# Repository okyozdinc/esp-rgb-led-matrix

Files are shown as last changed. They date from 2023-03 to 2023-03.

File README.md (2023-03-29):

# PIXELIX <!-- omit in toc -->
PIXELIX

Full RGB LED matrix, based on an ESP32 and WS2812B LEDs.






pixelix (https://www.youtube.com/watch?v=dik8Rm6f3o0 "Pixelix")
pixelix (https://www.youtube.com/watch?v=UCjJCI5JShY "Pixelix - Remote Button")

- [Motivation](#motivation)
- [Overview](#overview)
  - [Original setup](#original-setup)
  - [Others](#others)
- [Installation](#installation)
- [Very First Startup](#very-first-startup)
  - [Variant 1: Configure wifi station SSID and passphrase with the browser](#variant-1-configure-wifi-station-ssid-and-passphrase-with-the-browser)
  - [Variant 2: Configure wifi station SSID and passphrase with the terminal](#variant-2-configure-wifi-station-ssid-and-passphrase-with-the-terminal)
  - [Pixelix Is Ready](#pixelix-is-ready)
- [User Interface](#user-interface)
- [Documentation](#documentation)
- [Used Libraries](#used-libraries)
- [FAQ](#faq)
  - [Where to change panel topology of the LED matrix?](#where-to-change-panel-topology-of-the-led-matrix)
  - [How to change text properties?](#how-to-change-text-properties)
  - [The display only shows a error code, like "E4". What does that mean?](#the-display-only-shows-a-error-code-like-e4-what-does-that-mean)
  - [How can I use animated icons?](#how-can-i-use-animated-icons)
  - [How do I know that my sensor is recognized?](#how-do-i-know-that-my-sensor-is-recognized)
  - [Why do I see sometimes values from the LDR in the SensorPlugin, although no LDR is installed?](#why-do-i-see-sometimes-values-from-the-ldr-in-the-sensorplugin-although-no-ldr-is-installed)
  - [How can I use alternative icons?](#how-can-i-use-alternative-icons)
  - [Is it possible to use a font with 8px height?](#is-it-possible-to-use-a-font-with-8px-height)
  - [How to configure the date/time format?](#how-to-configure-the-datetime-format)
- [Issues, Ideas And Bugs](#issues-ideas-and-bugs)
- [License](#license)
- [Contribution](#contribution)

# Motivation
I want to have a remote display to show multiple kind of information, running 24/7 reliable. Connected over wifi to the local network, it can be controlled via REST API or websocket.

| Some impressions | |
| - | - |
| TimePlugin | DatePlugin |
| IconTextLampPlugin | IconTextPlugin |
| WifiStatusPlugin | ... |

# Overview

The firmware contains a plugin concept (at compile time) to provide different functionalities. Each plugin can create its own layout and place the information as required. If you are only interested in showing just text provided via REST API, choose the JustTextPlugin. It uses the whole display size and will scroll text automatically. Sometimes in front of the text a nice icon is required, in this case choose the IconTextPlugin. These are only examples and you will find more in the [plugin list](./doc/PLUGINS.md).

A little bit more detail about the generic plugins and the first idea can be found in this [rough overview](./doc/Overview.pdf).

## Original setup
The original setup during development and the first release was:
* [ESP32 DevKitV1](https://github.com/playelek/pinout-doit-32devkitv1)
* WS2812B 5050 8x32 RGB Flexible LED Matrix Panel
* Power supply 5 V / 4 A

The following shows the absolute minimal wiring setup:

PixelixMinimalSetup

> :warning: **If you power all via USB**: Be very careful, because it may destroy your esp32 board if the LED current gets too high. Avoid increasing the LED display brightness or filling it complete with white pixels. Please use a external power supply with at least 5V / 4A.

## Others

In the meantime several other boards are supported as well. You can see them in the platformio configuration (platformio.ini) or the [list of boards](./doc/boards/README.md).

Additional supported variants, which were original not in focus:
* [LILYGO&reg; TTGO T-Display ESP32 WiFi and Bluetooth Module Development Board For Arduino 1.14 Inch LCD](http://www.lilygo.cn/prod_view.aspx?TypeId=50033&Id=1126&FId=t3:50033:3)
* [LILYGO&reg; T-Display ESP32-S3 1.9 inch ST7789 LCD Display Touch Screen Development Board](https://www.lilygo.cc/products/t-display-s3)

Although Pixelix was designed to show information, that is pushed or pulled via REST API, the following sensors can be directly connected and evaluated:
* Temperature and humidity sensors DHTx
* Temperature and humidity sensors SHT3x
* Digitial microphone INMP441 for some sound reactive stuff.

# Installation
The following steps are necessary for the first time and to get PIXELIX initial running on the target. Once it runs, later on the firmware and filesystem can be updated via the PIXELIX webinterface.

1. Setup the [toolchain](./doc/config/TOOLCHAIN-INSTALLATION.md).
2. [Build the software](./doc/config/SW-BUILD.md) and check whether the toolchain works.
3. [Upload/Update the software and firmware](./doc/config/SW-UPDATE.md) to the target.
4. Verify that the LED panel topology is correct and you see the "Hello World" on the display.

Note, that the LED panel topology and the display width/height can currently not be changed in the web interface. If its necessary, adapt first in ```./lib/HalLedMatrix/Board.h``` the _width_ and _height_ according your LED matrix. In the ```./lib/HalLedMatrix/LedMatrix.h``` file you have to change the member variable _m\_topo_ according to your physical panel topology. Take a look how your pixels are wired on the pcb and use the following page to choose the right one: https://github.com/Makuna/NeoPixelBus/wiki/Layout-objects

# Very First Startup
If the device starts the very first time, the wifi station SSID and passphrase settings are empty. They can be configured in two possible ways:
1. Using the browser and set them in the captive portal.
2. Using a terminal connecting via usb.

## Variant 1: Configure wifi station SSID and passphrase with the browser
Restart the device and keep the button pressed until it shows the SSID of the wifi access point, spawned by Pixelix. Search for it with your mobile device and connect.
* SSID: **pixelix**
* Passphrase: **Luke, I am your father.**

Depended on the type of device you are using for connecting to Pixelix, you may get a notification that further information is necessary and automatically routed to the captive portal. In any other case enter the URL http://192.168.4.1 in the browser address field.

Use the following default credentials to get access to the Pixelix webinterface:
* User: **luke**
* Password: **skywalker**

## Variant 2: Configure wifi station SSID and passphrase with the terminal
Connect Pixelix with your PC via usb and start a terminal. Use the following commands to set the wifi SSID and passphrase of your home wifi network:
* Write wifi passphrase: ```write wifi passphrase <your-passphrase>```
* Write wifi SSID: ```write wifi ssid <your-ssid>```
* Restart Pixelix: ```reset```

## Pixelix Is Ready
After configuration, restart again and voila, Pixelix will be available in your wifi network.

For changing whats displayed, go to its webinterface. Use the same credentials than for the captive portal in variant 1. In the "Display" page you can change it according to your needs.

# User Interface
* The user button provides several features:
    * On short pulse: Activates the next slot.
    * Two short pulses: Activates next fade effect.
    * Five short pulses: IP address is shown.
    * Long pressed: Increases the display brightness until maximum and then decreases until minimum. After that it will again increases it and so on.
* If the display's location is hard to reach, the virtual user button can be used. It is controllable via REST API and perfect for remote buttons like the [Shelly Button 1](https://shelly.cloud/products/shelly-button-1-smart-home-automation-device/).
* If a ambilight sensor (LDR) is connected, the display brightness is automatically adapted.
* The web interface provides the possibility to install plugins, control their duration in the slots and etc.
* Some plugin's spawn a dedicated REST API, see the web page of the plugin or have a look to the REST API documentation.

Note, the websocket interface is currently only used as a service in the web interface.

# Documentation
For more information, see the [documentation](./doc/README.md).

# Used Libraries
* [Arduino](https://github.com/platformio/platform-espressif32) - ESP32 Arduino framework - Apache-2.0 License
* [NeoPixelBus](https://github.com/Makuna/NeoPixelBus) - Controlling the LED matrix with hardware support (RMT) - LGPL-3.0 License
* [ESPAsyncWebServer](https://github.com/me-no-dev/ESPAsyncWebServer) - Webserver - LGPL-2.1 License
* [AsyncTCPSock](https://github.com/yubox-node-org/AsyncTCPSock) - TCP library, Reimplementation of the API of me-no-dev/AsyncTCP using high-level BSD sockets - LGPL-3.0 License
* [ArduinoJson](https://arduinojson.org/) - JSON handling - MIT License
* [StreamUtils](https://github.com/bblanchon/ArduinoStreamUtils) - Stream utilities - MIT License
* [Bootstrap](https://getbootstrap.com/) - CSS Framework - MIT License
* [POPPER JS](https://popper.js.org/) - POPPER JS - MIT License
* [jQuery](https://jquery.com/) - Javascript librariy for DOM handling - MIT License
* [Adafruit Unified Sensor Driver](https://github.com/adafruit/Adafruit_Sensor) - A unified sensor abstraction layer. - Apache License 2.0 License
* [Adafruit DHT sensor library](https://github.com/adafruit/DHT-sensor-library) - An Arduino library for the DHT series of low-cost temperature/humidity sensors. - MIT License
* [arduino-sht](https://github.com/Sensirion/arduino-sht) - An Arduino library for reading the SHT3x family of temperature and humidity sensors. - BSD-3-Clause License
* [TFT_eSPI](https://github.com/Bodmer/TFT_eSPI) - Arduino and PlatformIO IDE compatible TFT library optimised for the Raspberry Pi Pico (RP2040), STM32, ESP8266 and ESP32 that supports different driver chips - Mixed licenses: MIT, BSD, FreeBSD
* [arduinoFFT](https://github.com/kosme/arduinoFFT) - Fast Fourier Transform for Arduino. - GPL 3.0 License
* [mufonts](https://github.com/muwerk/mufonts) - A collection of fonts compatible with Adafruit GFX library. These fonts were developed when creating various samples for mupplet display code. - MIT License
* [JSZip](https://github.com/Stuk/jszip) - A library for creating, reading and editing .zip files with JavaScript, with a lovely and simple API. - MIT License
* [JSZipUtils](https://github.com/Stuk/jszip-utils) - A collection of cross-browser utilities to go along with JSZip. - MIT License
* [FileSaver.js](https://github.com/eligrey/FileSaver.js) - FileSaver.js is the solution to saving files on the client-side. - MIT License
* [Arduino client for MQTT](https://github.com/knolleary/pubsubclient) - This library provides a client for doing simple publish/subscribe messaging with a server that supports MQTT. - MIT License

# FAQ

## Where to change panel topology of the LED matrix?
First adapt in ```./lib/HalLedMatrix/Board.h``` the _width_ and _height_ according your LED matrix.

In the ```./lib/HalLedMatrix/LedMatrix.h``` file you have to change the member variable _m\_topo_ according to your physical panel topology. Take a look how your pixels are wired on the pcb and use the following page to choose the right one: https://github.com/Makuna/NeoPixelBus/wiki/Layout-objects

## How to change text properties?
Text properties can be changed using different keywords added to the string to be displayed.  
In order to be able to use these keywords, they must be prefixed by a backslash, otherwise they will only be treated as text.

The following keywords are available:
Keyword   | Description
----------|---------------------------------
\\#RRGGBB | Change text color (RRGGBB in hex)
\lalign   | Alignment left
\ralign   | Alignment right
\calign   | Alignment center

**Note**
- If theses keywords are used within the sourcecode they have to be prefixed with two backslashes (one additional for escaping).
- If these keywords are used via the [REST API](https://app.swaggerhub.com/apis/BlueAndi/Pixelix/1.2.0) all unsafe ASCII characters must be replaced by the respective percent encoding (see also [ASCII Encoding Reference](https://www.w3schools.com/tags/ref_urlencode.ASP)).
- The keywords can be combined.  

**Examples**

Sourcecode   | URL   | Result
----------|--------------------|-------------
\\\lalign\\\\#ff0000Hi! | %5Clalign%23ff0000Hi! | I<span style="color:red">Hi!</span>&nbsp;&nbsp;&nbsp;&nbsp;&nbsp;&nbsp;&nbsp;&nbsp;I
\\\calign\\#ff0000Hi! | %5Ccalign%23ff0000Hi! | I&nbsp;&nbsp;&nbsp;&nbsp;<span style="color:red">Hi!</span>&nbsp;&nbsp;&nbsp;&nbsp;I
\\\ralign\\#ff0000Hi! | %5Cralign%23ff0000Hi!| I&nbsp;&nbsp;&nbsp;&nbsp;&nbsp;&nbsp;&nbsp;&nbsp;<span style="color:red">Hi!</span>I

## The display only shows a error code, like "E4". What does that mean?

This is a low level error code. Please have a look into the following table.

| Error code | Description |
| --- | --- |
| E1 | Something happened, which can not be further explained, but was fatal. |
| E2 | There is a problem with the two-wire (i2c) interface. |
| E3 | There is no user button available. |
| E4 | Bad filesystem, did you explicit program the filesystem too? If not, please upload it. |
| E5 | The display manager didn't start up. |
| E6 | The system message handler didn't start up. |
| E7 | The update manager didn't start up. |

## How can I use animated icons?
Upload first the bitmap texture image (.bmp) and afterwards the sprite sheet file (.sprite). See the details [here](./doc/SPRITESHEET.md).

## How do I know that my sensor is recognized?

1. Check the log output from USB (not via web interface) right after startup (at this point WiFi is not connected yet).
2. Install the SensorPlugin and open the SensorPlugin website. There the sensor should be shown in the drop-down.

## Why do I see sometimes values from the LDR in the SensorPlugin, although no LDR is installed?

The LDR pin is configured as input (ADC) and it seems that the pin is floating, because there is the ext. pull-down missing.

## How can I use alternative icons?

Find details [here](./doc/ICONS.md).

## Is it possible to use a font with 8px height?
There are three font types defined:
* default (6px height)
* normal (6px height)
* large (8px height)

Note, the default font type is "normal".

The font type can be selected per plugin instance in the settings web page.

Example:
```json
{
    "name": "JustTextPlugin",
    "uid": 32690,
    "alias": "",
    "fontType": "large"
}
```

Not all plugin may support this in case they get conflicts with their layout.
If a plugin don't support it, it will use the default font type.

## How to configure the date/time format?
The date/time format used by plugins, e.g. the DateTimePlugin or the SunrisePlugin, can be configured in their configuration JSON file. Use the file editor in the web interface to modify it according to your needs. The file can be found in the ```/configuration``` folder and the filename is ```<PLUGIN-UID>.json```. The format specifiers following [strftime()](https://cplusplus.com/reference/ctime/strftime/).

Examples:
* ```%I:%M %p```: 02:30 PM
* ```%H:%M```: 14:30
* ```%m/%d```: 11/12
* ```%d.%m.```: 11.12.
* ```%d - %b```: 11 - Nov

You can colorize it by using the [text properties](#how-to-change-text-properties).

# Issues, Ideas And Bugs
If you have further ideas or you found some bugs, great! Create a [issue](https://github.com/BlueAndi/esp-rgb-led-matrix/issues) or if you are able and willing to fix it by yourself, clone the repository and create a pull request.

# License
The whole source code is published under the [MIT license](http://choosealicense.com/licenses/mit/).
Consider the different licenses of the used third party libraries too!

# Contribution
Unless you explicitly state otherwise, any contribution intentionally submitted for inclusion in the work by you, shall be licensed as above, without any
additional terms or conditions.

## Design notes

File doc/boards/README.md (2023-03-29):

# PIXELIX <!-- omit in toc -->
PIXELIX



# Boards <!-- omit in toc -->
Pixelix supports different ESP32 development boards. Own PCBs were developed too for easier assembling of e.g. the LED matrix, sensors, etc.

To find out which part shall be connected to which pin of your development board you can see in the following chapters.

- [Pixelix Board v1.5](#pixelix-board-v15)
- [Pixelix Board v2.0](#pixelix-board-v20)
- [Development Boards](#development-boards)
  - [DOIT ESP32 DEVKIT V1](#doit-esp32-devkit-v1)
  - [DOIT ESP32 DEVKIT V4](#doit-esp32-devkit-v4)
  - [ESP32 NodeMCU](#esp32-nodemcu)
  - [AZ-Delivery ESP-32 Dev Kit C V4](#az-delivery-esp-32-dev-kit-c-v4)
  - [LILYGO® TTGO ESP32 T-Display](#lilygo-ttgo-esp32-t-display)
  - [LILYGO® ESP32 T-Display S3](#lilygo-esp32-t-display-s3)

# Pixelix Board v1.5
This board was original developed with a ESP32 DevKit V1 development board as piggy bag.
* [Hardware description](./pixelix/v1.5/ELECTRONIC.md)
* [Bill of material](./pixelix/v1.5/BOM.md)
* [Pinning](../../lib/HalLedMatrix/Board.h)
* [Schematic](./pixelix/v1.5/schematics/)
* [PCB](./pixelix/v1.5/pcb/)
* [Housing Part 1](https://www.thingiverse.com/thing:2791276)
* [Housing Part 2](https://www.thingiverse.com/thing:3884621)

# Pixelix Board v2.0
The Pixelix board v2.0 is the successor of Pixelix board v1.5. It was designed for ESP32 DevKit V4 (4 MB flash) and the Adafruit ESP32 Feather V2 (8 MB flash) development board as piggy bag.
* [Hardware description](./pixelix/v2.0/ELECTRONIC.md)
* [Bill of material](./pixelix/v2.0/BOM.md)
* [Pinning](../../lib/HalLedMatrix/Board.h)
* [Housing](./pixelix/v2.0/3D-files/)

# Development Boards

## DOIT ESP32 DEVKIT V1
* [Pinning](../../lib/HalLedMatrix/Board.h) (equal to Pixelix boards)

## DOIT ESP32 DEVKIT V4
* [Pinning](../../lib/HalLedMatrix/Board.h) (equal to Pixelix boards)

## ESP32 NodeMCU
* [Pinning](../../lib/HalLedMatrix/Board.h) (equal to Pixelix boards)

## AZ-Delivery ESP-32 Dev Kit C V4
* Manufacturer: [AZ-Delivery](https://www.az-delivery.de/products/esp-32-dev-kit-c-v4)
* [Pinning](../../lib/HalLedMatrix/Board.h) (equal to Pixelix boards)

## LILYGO&reg; TTGO ESP32 T-Display
The LILYGO&reg; TTGO ESP32 T-Display development board is handled separately, because the onboard display is used instead of a external LED matrix.

* Manufacturer: [Lilygo](http://www.lilygo.cn/prod_view.aspx?TypeId=50033&Id=1126&FId=t3:50033:3)
* [Pinning](../../lib/HalTftDisplay/Board.h)

## LILYGO&reg; ESP32 T-Display S3
The LILYGO&reg; ESP32 T-Display S3 development board is handled separately, because the onboard display is used instead of a external LED matrix.

* Manufacturer: [Lilygo](https://www.lilygo.cc/products/t-display-s3)
* [Pinning](../../lib/HalTftDisplay/Board.h)

# Issues, Ideas And Bugs <!-- omit in toc -->
If you have further ideas or you found some bugs, great! Create a [issue](https://github.com/BlueAndi/esp-rgb-led-matrix/issues) or if you are able and willing to fix it by yourself, clone the repository and create a pull request.

# License <!-- omit in toc -->
The whole source code is published under the [MIT license](http://choosealicense.com/licenses/mit/).
Consider the different licenses of the used third party libraries too!

# Contribution <!-- omit in toc -->
Unless you explicitly state otherwise, any contribution intentionally submitted for inclusion in the work by you, shall be licensed as above, without any
additional terms or conditions.

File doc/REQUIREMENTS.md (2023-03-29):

# PIXELIX <!-- omit in toc -->
PIXELIX



# Requirements <!-- omit in toc -->

- [General](#general)
- [Communication](#communication)
- [User Interaction](#user-interaction)
  - [Wifi](#wifi)
  - [REST](#rest)
  - [Websocket](#websocket)
- [Firmware update](#firmware-update)
- [TCP/IP Server](#tcpip-server)
- [Brightness Control](#brightness-control)
- [Real Time Clock](#real-time-clock)
- [Issues, Ideas And Bugs](#issues-ideas-and-bugs)
- [License](#license)
- [Contribution](#contribution)

Next available REQ id: 21

# General
* REQ-01: The display shall be able to show bitmaps and text.
* REQ-02: The display shall be able to show animations.

# Communication
* REQ-03: The communication with the display shall be via wifi.
* REQ-04: The display shall provide a [REST](https://en.wikipedia.org/wiki/Representational_state_transfer) API to exchange [JSON](https://en.wikipedia.org/wiki/JSON).
* REQ-05: The display shall provide a [websocket](https://en.wikipedia.org/wiki/WebSocket) interface.

# User Interaction
* REQ-10: The display shall provide a user button for user interaction.
* REQ-17: The display shall provide a reset button.

## Wifi

* REQ-07: The display shall setting up an wifi access point on user demand (via user button) after a power-cycle.
* REQ-08: The wifi access point shall have the following default configuration:
    * SSID: pixelix
    * Security: WPA
    * Password: "Luke, I am your father."
* REQ-09: If a remote wifi network is configured, the display shall automatically connect after a power-cycle.

## REST

* REQ-19: A REST interface shall be provided to control the display or retrieve information.

## Websocket

* REQ-20: A websocket interface shall be provided to control the display or retrieve information.

# Firmware update
* REQ-06: The firmware shall be updated over the air.
* REQ-14: The firmware update shall be protected against malicious access via authorization.

# TCP/IP Server

* REQ-11: The display shall provide a [HTTP](https://en.wikipedia.org/wiki/Hypertext_Transfer_Protocol)/[HTTPS](https://en.wikipedia.org/wiki/Hypertext_Transfer_Protocol_Secure) webserver.
* REQ-12: The user shall be able to configure a remote wifi network, if a access point is spawned.
* REQ-12: The webserver shall be protected against malicious access via authorization.
* REQ-13: The webserver shall not run during an firmware update.

# Brightness Control
* REQ-15: The display brightness shall be automatically adapted to the environment.
* REQ-16: The max. display brightness shall be limited to avoid a high LED matrix current, which destroys electronic parts.

# Real Time Clock
* REQ-18: The display shall contain a real time clock, used for power modes or a clock.

# Issues, Ideas And Bugs
If you have further ideas or you found some bugs, great! Create a [issue](https://github.com/BlueAndi/esp-rgb-led-matrix/issues) or if you are able and willing to fix it by yourself, clone the repository and create a pull request.

# License
The whole source code is published under the [MIT license](http://choosealicense.com/licenses/mit/).
Consider the different licenses of the used third party libraries too!

# Contribution
Unless you explicitly state otherwise, any contribution intentionally submitted for inclusion in the work by you, shall be licensed as above, without any
additional terms or conditions.

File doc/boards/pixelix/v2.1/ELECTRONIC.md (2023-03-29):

# PIXELIX <!-- omit in toc -->
PIXELIX



# Electronic <!-- omit in toc -->

- [Version](#version)
- [System Diagram](#system-diagram)
- [Differences to v1.5](#differences-to-v15)
- [Development Boards](#development-boards)
  - [ESP32 DevKit C V4](#esp32-devkit-c-v4)
  - [Adafruit ESP32 Feather V2](#adafruit-esp32-feather-v2)
- [Strapping Pins](#strapping-pins)
- [Input Only Pins](#input-only-pins)
- [Analog Pins](#analog-pins)
- [JTAG](#jtag)
- [LED Matrix](#led-matrix)
- [Ambient Light Sensor](#ambient-light-sensor)
- [Issues, Ideas And Bugs](#issues-ideas-and-bugs)
- [License](#license)
- [Contribution](#contribution)

# Version

PCB board v2.0

# System Diagram

system-diagram

# Differences to v1.5

* The clock crystal in v1.5 was removed, because it wasn't used.
* The I2S interface was added for digital microphones, like the INMP441.
* ESP32 Dev Kit C V4 will be used instead of ESP32 DEVKIT V1.
* It is also possible to use the Adafruit ESP32 Feather V2 instead of the ESP32 Dev Kit C V4.

# Development Boards 
## ESP32 DevKit C V4

ESP32 DevKitV4 Pinout

| ESP32 DevKit V4 Pin | ESP32 DevKit V4 Pin Header | WROOM32 Pin | Notes | Usage |
| --- | --- | --- | --- | --- |
| 3V3 | J1-1 | 3V3 | 3.3 V output | +3V3|
| EN | J1-2 | EN | 10k Pull-Up; Button on ESP32 DevKit V4; Active High | RESET |
| VP | J1-3 | GPIO 36 (VP) | Input only! See ESP32 tech. reference manual, chapter 4.1 (no internal pull-up/down circuitry) | - |
| VN | J1-4 | GPIO 39 (VN) | Input only! See ESP32 tech. reference manual, chapter 4.1 (no internal pull-up/down circuitry) | - |
| 34 | J1-5 | GPIO 34 | Input only! See ESP32 tech. reference manual, chapter 4.1 (no internal pull-up/down circuitry) | LDR Analog In |
| 35 | J1-6 | GPIO 35 | Input only! See ESP32 tech. reference manual, chapter 4.1 (no internal pull-up/down circuitry) | - |
| 32 | J1-7 | GPIO 32 | Input only! See ESP32 tech. reference manual, chapter 4.1 (no internal pull-up/down circuitry) | - |
| 33 | J1-8 | GPIO 33 | I2S microphone serial data. | I2S_Data_IN |
| 25 | J1-9 | GPIO 25 | I2S microphone word select. | I2S_WS |
| 26 | J1-10 | GPIO 26 | I2S microphone serial clock. | I2S_CLK |
| 27 | J1-11 | GPIO 27 | Data Out to LED matrix | LV-DATA-OUT |
| 14 | J1-12 | GPIO 14 | Output PWM at power-up! | MTMS |
| 12 | J1-13 | GPIO 12 | Strapping pin; Fails if high at power-up, therefore not used. | MTDI |
| GND | J1-14 | GND | Ground | GND |
| 13 | J1-15 | GPIO 13 | - | MTCK |
| 2 | J1-16 | GPIO 9 (D2) | Pin shared with Flash Memory (Can´t be used as regular Pin) | - |
| 3 | J1-17 | GPIO 10 (D3) | Pin shared with Flash Memory (Can´t be used as regular Pin) | - |
| CMD | J1-18 | GPIO 11 (CMD) | - | - |
| 5V | J1-19 | 5V0 | external power supply | VCC-PROTECTED |
| GND | J2-1 | GND | Ground | GND |
| 23 | J2-2 | GPIO 23 | - | Test Pin |
| 22 | J2-3 | GPIO 22 | I2C SCL (Arduino Standard) | I2C SCL |
| TX0 | J2-4 | GPIO 1 (TX0) | USB TX | - |
| RX0 | J2-5 | GPIO 3 (RX0) | USB RX | - |
| 21 | J2-6 | GPIO 21 | I2C SDA (Arduino Standard) | I2C SDA |
| GND | J2-7 | GND | Ground | GND |
| 19 | J2-8 | GPIO 19 | - | - |
| 18 | J2-9 | GPIO 18 | - | - |
| 5 | J2-10 | GPIO 5 | Strapping pin; 10k Pull-Up on ESP32 DevKit V4 | (DHT In) |
| 17 | J2-11 | GPIO 17 (TX2) | - | - |
| 16 | J2-12 | GPIO 16 (RX2) | - | - |
| 4 | J2-13 | GPIO 4 | User Button | USER-BUTTON |
| 0 | J2-14 | GPIO 0 | Strapping pin, 10k Pull-Up; Button on ESP32 DevKit V4, closing to GND | - |
| 2 | J2-15 | GPIO 2 | Strapping pin; Onboard LED on ESP32 DevKit V4 | Onboard LED |
| 15 | J2-16 | GPIO 15 | Strapping pin | MTDO |
| D1 | J2-17 | GPIO 8 (D1) | - | - |
| D0 | J2-18 | GPIO 7 (D0) | - | - |
| CLK | J2-19 | GPIO 6 (SCK) | - | - |

## Adafruit ESP32 Feather V2
Adafruit ESP32 Feather V2 Pinout

| Adafruit ESP32 Feather V2 Pin | Adafruit Feather V2 Pin Header | WROOM32 Pin | Notes | Usage |
| --- | --- | --- | --- | --- |
| RST | J1-1 | RESET | The reset pin is used for the reset button, but can also be used standalone. Tie it to ground to reset the board. Pull-Up; Button on Feather V2; Active High | RESET |
| 3V | J1-2 | 3.3V | 3.3 V output | +3V3 |
| NC | J1-3 | - | Not Connected | - | 
| GND | J1-4 | GND | Ground | GND |
| A0 | J1-5 | GPIO 26 (A0) | This is also DAC2. It uses ADC2 | I2S_CLK |
| A1 | J1-6 | GPIO 25 (A1) | This is also DAC1. It uses ADC2 | I2S_WS |
| A2 | J1-7 | GPIO 34 (A2) | It is input/ADC only. It uses ADC1 | LDR-ANALOG-IN |
| A3 | J1-8 | GPIO 39 (A3) | It is input/ADC only. It uses ADC1 | - |
| A4 | J1-9 | GPIO 36 (A4) | It is input/ADC only. It uses ADC1 | - |
| A5 | J1-10 | GPIO 4 (A5) | It uses ADC2 | USER-BUTTON |
| SCK | J1-11 | GPIO 5 | This is the SPI clock pin | (DHT In) |
| MO | J1-12 | GPIO 19 | This is the SPI Microcontroller Out / Serial In (MOSI) pin (Adafruit Feather V2 Schematic-Symbol is wrong! -> IO18) | - |
| MI | J1-13 | GPIO 21 | This is the SPI Microcontroller In / Serial Out (MISO) pin (Adafruit Feather V2 Schematic-Symbol is wrong! -> IO19) | - |
| RX | J1-14 | GPIO 7 | This is the UART RX (receive) pin | - |
| TX | J1-15 | GPIO 8 | This is the UART TX (transmit) pin | - |
| 37 | J1-16 | GPIO 37 | It is input/ADC only. It uses ADC1 | - |
| GND | J2-1 | GND | Ground; **JST connector** | GND |
| BAT | J2-2 | VBAT | This is the positive voltage to the **JST connector** for the optional lipoly battery | - |
| BAT | J3-1 | VBAT | This is the positive voltage from the JST connector for the optional lipoly battery | - |
| EN | J3-2 | EN | This is the 3.3V regulator's enable pin. It's pulled up, so connect to ground to disable the 3.3V regulator | - |
| USB | J3-3 | VBUS | This is the positive voltage to/from the USB-C connector if connected | VCC-PROTECTED |
| 13 | J3-4 | GPIO 13 | It uses ADC2; Onboard LED | MTCK and Onboard LED |
| 12 | J3-5 | GPIO 12 | It uses ADC2 | MTDI |
| 27 | J3-6 | GPIO 27 | It uses ADC2 | LV-DATA-OUT |
| 33 | J3-7 | GPIO 33 | It uses ADC1 | I2S_Data_IN |
| 15 | J3-8 | GPIO 15 | It uses ADC2 | MTDO |
| 32 | J3-9 | GPIO 32 | It uses ADC1 | Test Pin |
| 14 | J3-10 | GPIO 14 | It uses ADC2 | MTMS |
| SCL | J3-11 | GPIO 20 (SCL) | I2C clock | I2C SCL (Adafruit Feather V2 Schematic-Symbol is wrong! -> IO22) |
| SDA | J3-12 | GPIO 22 (SDA) | I2C data | I2C SDA (Adafruit Feather V2 Schematic-Symbol is wrong! -> IO23)|

# Strapping Pins

The following table shows the strapping bit status on the ESP32 DevKit C V4 board. See also ESP32 series datasheet chapter 2.4

| Pin | Default | Function 1 | Function 2 |
| --- | --- | --- | --- |
| Voltage of internal LDO (VDD_SDIO) |
| Pin | Default | 3.3 V | 1.8 V |
| GPIO 12 (MTDI) | Low | Low | High |
Result: 3.3 V

| Pin | Default | Function 1 | Function 2 |
| --- | --- | --- | --- |
| Booting mode |
| Pin | Default | SPI Boot | Download Boot |
| GPIO 0 | High | High | Low |
| GPIO 2 | Low | Don't care | 0 |
Result: SPI Boot

| Pin | Default | Function 1 | Function 2 |
| --- | --- | --- | --- |
| Enabling/Disabling debugging log print over U0TXD during booting |
| Pin | Default | U0TXD Toggling | U0TXD Silent |
| GPIO 15 (MTDO) | High | High | Low |
Result: U0TXD Toggling

| Pin | Default | Function 1 | Function 2 | Function 3 | Function 4 |
| --- | --- | --- | --- | --- | --- |
| Timing of SDIO slave |
| Pin | Default | Falling-edge Sampling | Falling-edge Sampling | Rising-edge Sampling | Rising-edge Sampling |
| GPIO 15 (MTDO) | High | Low | Low | High | High |
| GPIO 5 | High | Low | High | Low | High |
Result: Rising-edge Sampling

# Input Only Pins
GPIOs 34 to 39 are input only pins. These pins don’t have internal pull-ups or pull-down resistors. They can’t be used as outputs, so use these pins only as inputs.

# Analog Pins
ADC2 is used by the Wi-Fi driver. Therefore the application can only use ADC2 when the Wi-Fi driver has not started.
See [Analog to Digital Converter](https://docs.espressif.com/projects/esp-idf/en/latest/api-reference/peripherals/adc.html).

# JTAG

| Pin | Function |
| --- | --- |
| MTDI (GPIO 12) | Test Data Input |
| MTCK (GPIO 13) | Test Clock |
| MTMS (GPIO 14) | Test Mode Select |
| MTDO (GPIO 15) | Test Data Output |

See [ESP-PROG](https://docs.platformio.org/en/latest/plus/debug-tools/esp-prog.html#debugging-tool-esp-prog).

# LED Matrix

The LED matrix consists of 8 x 32 WS2812B LEDs. Each LED has a max. current of 60 mA, which would result in a max. power consumption of 5 V / 15.36 A. The flexible LED panel matrix would be damaged with this high nominal power consumption, therefore it shall be limited to 5 V / 4 A.

Input voltage level:
* High - Min. 0.7 * VDD
  * => 0.7 * 5 V = 3.5 V
* Low - Max. 0.3 * VDD
  * => 0.3 * 5 V = 1.5 V

The i/o pins of the ESP32 are running with a 3.3 V level, which could cause a problem in detection a high!
Therefore the level must be shifted from 3.3 V to 5V.

# Ambient Light Sensor

The following table shows the output voltage, generated by a LDR like the GL5528 and a 1 k resistor. Both assembled as voltage divider.

| Ambient light | Ambient light | Photocell resistance | LDR + R | Voltage across R|
| --- | --- | --- | --- | --- |
| Moonlit night | 1 lux | 70 kΩ | 71 kΩ | 0.046 V |
| Dark room | 10 lux | 10 kΩ | 11 kΩ | 0.3 V |
| Dark overcast day / Bright room | 100 lux | 1.5 kΩ | 2.5 kΩ | 1.32 V |
| Overcast day | 1000 lux | 300 Ω | 1.3 kΩ | 2.538 V |
| Full daylight | 10,000 lux | 100 Ω | 1.1 kΩ | 3.0 V |

# Issues, Ideas And Bugs
If you have further ideas or you found some bugs, great! Create a [issue](https://github.com/BlueAndi/esp-rgb-led-matrix/issues) or if you are able and willing to fix it by yourself, clone the repository and create a pull request.

# License
The whole source code is published under the [MIT license](http://choosealicense.com/licenses/mit/).
Consider the different licenses of the used third party libraries too!

# Contribution
Unless you explicitly state otherwise, any contribution intentionally submitted for inclusion in the work by you, shall be licensed as above, without any
additional terms or conditions.

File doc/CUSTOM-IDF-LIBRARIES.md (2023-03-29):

# PIXELIX <!-- omit in toc -->
PIXELIX



# Building ESP-IDF Libraries for Arduino using custom sdkconfig options

- [Building ESP-IDF Libraries](#Building-ESP-ID-Libraries)
- [Purpose](#purpose)
- [Instructions](#instructions)
- [Issues, Ideas And Bugs](#issues-ideas-and-bugs)
- [License](#license)
- [Contribution](#contribution)

# Purpose

This tutorial explains how to re-compile the ESP-IDF Libraries using custom sdkconfig settings that are no usually available for the Arduino Core.
This has been done in a WSL (Ubuntu) environment to simplify any installation process.

# Instructions

1. Install all dependencies:

``` bash
sudo apt-get install git wget curl libssl-dev libncurses-dev flex bison gperf python python-pip python-setuptools python-serial python-click python-cryptography python-future python-pyparsing python-pyelftools cmake ninja-build ccache jq
```

2. Clone the [Espressif Library Builder](https://github.com/espressif/esp32-arduino-lib-builder) Github project.

``` bash
# Clone Repository
git clone https://github.com/espressif/esp32-arduino-lib-builder

# Change Directory
cd esp32-arduino-lib-builder
```

3. Add the desired configuration lines to the different configuration possibilities inside the `./configs` folder.

In order to activate the tracing facility of FreeRTOS, add the following lines at the end of `./configs/defconfig.common`:

```
CONFIG_FREERTOS_USE_TRACE_FACILITY=y
CONFIG_FREERTOS_USE_STATS_FORMATTING_FUNCTIONS=y
CONFIG_FREERTOS_VTASKLIST_INCLUDE_COREID=y
```

Note:
As this projects includes its own partition tables, it is necessary to **remove** those options that do not use the default partition tables from `./configs/defconfig.common`:

```
CONFIG_ESP_COREDUMP_ENABLE=y
CONFIG_ESP_COREDUMP_ENABLE_TO_FLASH=y
CONFIG_ESP_COREDUMP_DATA_FORMAT_ELF=y
CONFIG_ESP_COREDUMP_CHECKSUM_CRC32=y
CONFIG_ESP_COREDUMP_MAX_TASKS_NUM=64
CONFIG_ESP_COREDUMP_STACK_SIZE=1024
CONFIG_MBEDTLS_DYNAMIC_BUFFER=y
CONFIG_MBEDTLS_DYNAMIC_FREE_PEER_CERT=y
CONFIG_MBEDTLS_DYNAMIC_FREE_CONFIG_DATA=y
```

4. Run the build script.

``` bash
./build.sh
```

If only the `esp32` libraries are required, the compilation can be reduced by using:

``` bash
./build.sh -t esp32
```

5. Replace the libraries in the PlatformIO package folder `.../.platformio/packages/framework-arduinoespressif32/tools/sdk/esp32` with the `./out/tools/sdk/esp32` output folder.

# Issues, Ideas And Bugs
If you have further ideas or you found some bugs, great! Create a [issue](https://github.com/BlueAndi/esp-rgb-led-matrix/issues) or if you are able and willing to fix it by yourself, clone the repository and create a pull request.

# License
The whole source code is published under the [MIT license](http://choosealicense.com/licenses/mit/).
Consider the different licenses of the used third party libraries too!

# Contribution
Unless you explicitly state otherwise, any contribution intentionally submitted for inclusion in the work by you, shall be licensed as above, without any
additional terms or conditions.

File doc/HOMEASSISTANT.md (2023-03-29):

# PIXELIX <!-- omit in toc -->
PIXELIX



# Homeassistant REST API Wrapper for Plugins <!-- omit in toc -->
This is work in progress...
- [Purpose](#purpose)
- [Installation](#installation)
  - [Setting up REST command](#setting-up-rest-command)
  - [Import Blueprint](#import-blueprint)
  - [Generate an automation](#generate-an-automation)

# Purpose
If you want to display sensor data from your Homeassistant instance you can use this wrapper.
For now only the "JustText"-Plugin is supported.

# Installation
If you want to add the wrapper to your Homeassistant Instance you first need to add a REST command to your `configuration.yaml`

## Setting up REST command
Add the following lines of code to your `configuration.yaml`:
```yaml
rest_command:
  pixelix_just_text:
    url: 'http://192.168.178.10/rest/api/v1/display/uid/{{ uid }}/text?show={{ "%5C" + align + "%5C" + color + text }}'
    method: POST
```
You need to replace the IP `192.168.178.10` with your Pixelix instance IP.

## Import Blueprint
You can use this link to add the wrapper to your Homeassistant installation.



As an alternative you can copy the yaml to  `/config/blueprints/automation/homeassistant/`
You can find the raw YAML file [here](./homeassistant/pixelix-justtext.yaml "here")

## Generate an automation
First of all you need to make an "JustText"-Plugin-Slot in your Pixelix installation. Then note down the uid of the plugin.

Example Homeassistant Automation

The fields should be pretty self-explanatory.
Just note that you have to enter the sensor labels in the following format:
```
- Sensor Label 1
- Sensor Label 2
- Sensor Label 3
```
See it in the example screenshot above
**Important:** Each sensor entry **must have** an corresponding sensor label entry!

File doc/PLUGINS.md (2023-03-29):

# PIXELIX <!-- omit in toc -->
PIXELIX



# Plugins <!-- omit in toc -->
The content of the display can be configured by installing an individual set of plugins.
Each plugin is identified by its unique UID.

- [Generic plugins](#generic-plugins)
  - [IconTextPlugin](#icontextplugin)
  - [IconTextLampPlugin](#icontextlampplugin)
  - [JustTextPlugin](#justtextplugin)
  - [ThreeIconPlugin](#threeiconplugin)
- [Dedicated plugins](#dedicated-plugins)
  - [BTCQuotePlugin](#btcquoteplugin)
  - [CountdownPlugin](#countdownplugin)
  - [DateTimePlugin](#datetimeplugin)
  - [DDPPlugin](#ddpplugin)
    - [xlights Configuration](#xlights-configuration)
  - [FirePlugin](#fireplugin)
  - [GameOfLifePlugin](#gameoflifeplugin)
  - [GithubPlugin](#githubplugin)
  - [GruenbeckPlugin](#gruenbeckplugin)
  - [MatrixPlugin](#matrixplugin)
  - [OpenWeatherPlugin](#openweatherplugin)
  - [RainbowPlugin](#rainbowplugin)
  - [SensorPlugin](#sensorplugin)
  - [ShellyPlugSPlugin](#shellyplugsplugin)
  - [SignalDetectorPlugin](#signaldetectorplugin)
  - [SoundReactivePlugin](#soundreactiveplugin)
  - [SunrisePlugin](#sunriseplugin)
  - [SysMsgPlugin](#sysmsgplugin)
  - [TempHumidPlugin](#temphumidplugin)
  - [TestPlugin](#testplugin)
  - [VolumioPlugin](#volumioplugin)
  - [WifiStatusPlugin](#wifistatusplugin)
  - [WormPlugin](#wormplugin)
- [Issues, Ideas And Bugs](#issues-ideas-and-bugs)
- [License](#license)
- [Contribution](#contribution)

# Generic plugins
The generic plugins allow the user to control the different UI elements described in the plugin name via the [REST API](https://app.swaggerhub.com/apis/BlueAndi/Pixelix/1.2.0).

## IconTextPlugin
The IconTextPlugin shows an icon on left side, text on right side. If no text is set, the plugin will be skipped in the slot.\
Each part can be set separately via the [REST API](https://app.swaggerhub.com/apis/BlueAndi/Pixelix/1.2.0#/IconTextPlugin).

## IconTextLampPlugin
The IconTextLampPlugin shows an icon on left side, text on right side and lamps at the bottom.\
Each part can be set separately via the [REST API](https://app.swaggerhub.com/apis/BlueAndi/Pixelix/1.2.0#/IconTextLampPlugin).

## JustTextPlugin
The JustTextPlugin shows only text on the whole display. If no text is set, the plugin will be skipped in the slot.\
The text to be displayed can be set via the [REST API](https://app.swaggerhub.com/apis/BlueAndi/Pixelix/1.2.0#/JustTextPlugin).

## ThreeIconPlugin
The ThreeIconPlugin shows three icons on the display.\
Each icon can be set separately via the [REST API](https://app.swaggerhub.com/apis/BlueAndi/Pixelix/1.2.0#/ThreeIconPlugin).

# Dedicated plugins
Dedicated plugins are plugins which only serves one single purpose thy are only internally configurable.

## BTCQuotePlugin
The BTCQuotePlugin shows the current exchange rate from Bitcoin to USD.\
Powered by [CoinDesk](https://www.coindesk.com/price/bitcoin).

## CountdownPlugin
The CountdownPlugin shows the remaining days until a configured target date.\
Target date and the description of the target day (plural/singular form) can be set via the [REST API](https://app.swaggerhub.com/apis/BlueAndi/Pixelix/1.2.0#/CountdownPlugin).

## DateTimePlugin
The plugin shows the current time and/or date.

If date and time are configured, first the time will be shown for half of the slot duration and after it the date. It can be configured to show only the date or only the time as well.

Below the day of the week is shown, starting from the left with Monday.

Configure the date and time format in the plugin configuration JSON file. The format itself is according to strftime(). For colorization text properties can be added.

By default the local time (see timezone in the settings) is used. It can be overwritten by the plugin configuration.

It can be set what shall be shown via the [REST API](https://app.swaggerhub.com/apis/BlueAndi/Pixelix/1.2.0#/DateTimePlugin).

## DDPPlugin
The plugin setup a server supporting the Distributed Display Protocol (DDP), which is used e.g. by [xlights](https://www.xlights.org) or [LedFx](https://www.ledfx.app).

Supported formats:
* RGB with 24-bit per pixel

### xlights Configuration
* Add Ethernet controller
    * Name: Pixelix
    * IP Address: &lt;IP-ADDRESS&gt;
    * Protocol: DDP
* Add layout
    * Create new matrix
        * Name: Matrix8x32
    * Matrix
        * Strings: 8
        * Nodes/String: 32
        * Strands/String: 1
        * Starting Location: Top Left
        * Controller: Pixelix
    * Controller Connection
        * Port: 1
        * Protocol: LED Panel Matrix
    * String Properties
        * String Type: RGB Nodes
    * Appearance
        * Pixel Size: 10
        * Pixel Style: Square

## FirePlugin
The FirePlugin shows a animated fire on the display.

## GameOfLifePlugin
The GameOfLifePlugin shows the game of life game on the display.

## GithubPlugin
The plugin shows the stargazers count of a github repository.

## GruenbeckPlugin
The GruenbeckPlugin shows the remaining system capacity (parameter = D_Y_10_1 ) of the Gruenbeck softliQ SC18 via the system's RESTful webservice.\
The IP address of the Gruenbeck webserver can be set via the [REST API](https://app.swaggerhub.com/apis/BlueAndi/Pixelix/1.2.0#/GruenbeckPlugin).

## MatrixPlugin
The plugin shows the effect from the film "Matrix" over the whole display.

## OpenWeatherPlugin
The OpenWeatherPlugin shows the current weather condition (icon and temperature) and one additional information (uvIndex, humidity or windspeed) .\
Information provided by [OpenWeather](https://openweathermap.org/).\
In order to use the plugin an API key is necessary, see https://openweathermap.org/appid for further information.\
The coordinates (latitude & longitude) of your location, your API key and the desired additional information to be displayed can be set via the [REST API](https://app.swaggerhub.com/apis/BlueAndi/Pixelix/1.2.0#/OpenWeatherPlugin).

## RainbowPlugin
The RainbowPlugin shows an animated rainbow on the display.

## SensorPlugin
The plugin shows sensor values of the selected sensor channel.

## ShellyPlugSPlugin
The ShellyPlugSPlugin shows the current AC power being drawn via a Shelly PlugS, in watts.\
The IP address of the Shelly PlugS webserver can be set via the [REST API](https://app.swaggerhub.com/apis/BlueAndi/Pixelix/1.2.0#/ShellyPlugSPlugin).

## SignalDetectorPlugin
The plugin is able to detect a signal, which can be combined with up to 2 frequencies.\
Each frequency must be detected for a specific configureable time.\
As long as nothing is detected, the plugin will disable itself.\
If a signal is detected, it will be shown on the display for the configured slot duration. After slot duration timeout or user changed the slot, the plugin will be disabled until next signal detection. \
Additional a push notification can be configured. By default a GET is triggered. Using "GET" or "POST" as prefix its configureable. Example: "POST http://..."

## SoundReactivePlugin
The plugin shows octave frequency bands, depended on the environment sound.
Required: A digital microphone (INMP441) is required, connected to the I2S port.
The number of shown frequency bands can be set via the [REST API](https://app.swaggerhub.com/apis/BlueAndi/Pixelix/1.2.0#/SoundReactivePlugin).

## SunrisePlugin
The SunrisePlugin shows the current sunrise / sunset times for a configured location.\
The coordinates (latitude & longitude) of your location can be set via the [REST API]([REST.md#endpoint-base-uridisplayuidplugin-uidlocation](https://app.swaggerhub.com/apis/BlueAndi/Pixelix/1.2.0#/SunrisePlugin)).\
Powered by sunrise-sunset.org

Configure the time format in the plugin configuration JSON file. The format itself is according to strftime(). For colorization text properties can be added.

## SysMsgPlugin
The SysMsgPlugin is a system plugin, which is used to splash important information's to the user. Note, it can not be uninstalled.

## TempHumidPlugin
Th TempHumidPlugin displays the temperature (in °C) and Humidity (in %) based on the readings of sensor connected to Pixelix.

## TestPlugin
The TestPlugin can be used to check whether the LED matrix topology (layout) is correct or not.

## VolumioPlugin
The VolumioPlugin shows the current VOLUMIO state as icon and the played artist/title.\
If the VOLUMIO server is offline, the plugin gets automatically disabled, otherwise enabled.\
The host address of the Volumio webserver can be set via the [REST API](https://app.swaggerhub.com/apis/BlueAndi/Pixelix/1.2.0#/VolumioPlugin).

## WifiStatusPlugin
The WifiStatusPlugin shows the current wireless signal strength.

## WormPlugin
The plugin shows animated worms on the display. If they find some meal, they will grow up. If they eat too much, they will explode.

# Issues, Ideas And Bugs
If you have further ideas or you found some bugs, great! Create a [issue](https://github.com/BlueAndi/esp-rgb-led-matrix/issues) or if you are able and willing to fix it by yourself, clone the repository and create a pull request.

# License
The whole source code is published under the [MIT license](http://choosealicense.com/licenses/mit/).
Consider the different licenses of the used third party libraries too!

# Contribution
Unless you explicitly state otherwise, any contribution intentionally submitted for inclusion in the work by you, shall be licensed as above, without any
additional terms or conditions.

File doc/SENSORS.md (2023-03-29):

# PIXELIX <!-- omit in toc -->
PIXELIX



# Sensors

- [Sensors](#sensors)
- [Purpose](#purpose)
- [General](#general)
- [Ambient light sensor](#ambient-light-sensor)
  - [Photoresistor GL5528](#photoresistor-gl5528)
- [Temperature and humidity sensors](#temperature-and-humidity-sensors)
  - [DHTx (Proprietary one-wire)](#dhtx-proprietary-one-wire)
  - [SHT3x (I2C)](#sht3x-i2c)
- [Audio (digital micropohone with I2S)](#audio-digital-micropohone-with-i2s)
  - [INMP441](#inmp441)
- [Issues, Ideas And Bugs](#issues-ideas-and-bugs)
- [License](#license)
- [Contribution](#contribution)

# Purpose
Here is a list of supported sensors. Where they are connected, depends on the used [hardware board](./boards/README.md). Some of them need additional external parts e.g. the DHTx need a ext. 4.7kOhm pull-up resistor. Please check the corresponding datasheets.

# General
A "X" in the development board column means valid all development boards. Exceptions may be listed separately.

# Ambient light sensor

## Photoresistor GL5528

| Development Board | Photoresistor pin 1 | Photoresistor pin 2 |
| --- | --- | --- |
| X | Vcc | Pin 34 |
| Lilygo&reg; TTGO ESP32 T-Display | Vcc | Pin 32 |
| Lilygo&reg; ESP32 T-Display S3 | Vcc | Pin 10 |

# Temperature and humidity sensors

## DHTx (Proprietary one-wire)
* DHT11 (Proprietary one-wire)
* DHT12 (Proprietary one-wire)
* DHT21 (Proprietary one-wire)
* DHT22 (Proprietary one-wire)

| Development Board | DHTx pin 1 | DHTx pin 2 |
| --- | --- | --- |
| X | Vcc | Pin 5 |
| Lilygo&reg; TTGO ESP32 T-Display | Vcc | Pin 27 |
| Lilygo&reg; ESP32 T-Display S3 | Vcc | Pin 21 |

## SHT3x (I2C)

| Development Board | I2C SCL | I2C SDA |
| --- | --- | --- |
| X | Pin 22 | Pin 21 |
| Lilygo&reg; ESP32 T-Display S3 | Pin 17 | Pin 18 |

# Audio (digital micropohone with I2S)

## INMP441
Only the left channel is supported, therefore the L/R channel select signal shall be connected to GND.

| Development Board | Left/Right Clock (LRCL) | Data Output (DOUT) | Bit Clock (BCLK) | Left/Right Channel Select (L/R) | Chip Enable (CHIPEN) |
| --- | --- | --- | --- | --- | --- |
| X | Pin 25 | Pin 33 | Pin 26 | GND | Vcc |
| Lilygo&reg; ESP32 T-Display S3 | Pin 12 | Pin 18 | Pin 11 | GND | Vcc |

# Issues, Ideas And Bugs
If you have further ideas or you found some bugs, great! Create a [issue](https://github.com/BlueAndi/esp-rgb-led-matrix/issues) or if you are able and willing to fix it by yourself, clone the repository and create a pull request.

# License
The whole source code is published under the [MIT license](http://choosealicense.com/licenses/mit/).
Consider the different licenses of the used third party libraries too!

# Contribution
Unless you explicitly state otherwise, any contribution intentionally submitted for inclusion in the work by you, shall be licensed as above, without any
additional terms or conditions.

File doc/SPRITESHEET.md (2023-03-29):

# PIXELIX <!-- omit in toc -->
PIXELIX



# Sprite Sheet <!-- omit in toc -->

- [Purpose](#purpose)
- [Tools And Scripts](#tools-and-scripts)
- [Limitations](#limitations)
- [Issues, Ideas And Bugs](#issues-ideas-and-bugs)
- [License](#license)
- [Contribution](#contribution)

# Purpose
Use a sprite sheet for 2d animations.
The sprite sheet parameters are defined in a additional file to the bitmap file in JSON format. The file shall have the file extension ".sprite".

Example of a fire animation (see ./doc/spritesheet/example):
```json
{
    "texture": {
        "width": 40,
        "height": 8,
        "frames": 5,
        "frame": {
            "width": 8,
            "height": 8
        },
        "fps": 5,
        "repeat": true
    }
}
```

WifiStatusPlugin

The *texture* describes the bitmap texture which contains one or usually several sprites. The bounding box of a sprite is called *frame*.

Because a *texture* may not be filled with sprites, the number of frames (*frames*) is given. If the number of frames is not given, it will be assumed that the texture is completely filled.

The order of each frame is from top left to the right and in the next row again from left to right and so on. If not further specified, it will be automatically repeated. If only on animation cycle is required, it will be specified with *repeat* by setting it to "false".

The frames per second (fps) specifiy how fast the animation runs.

# Tools And Scripts

Use the ```./doc/spritesheet/create_sprite_sheet.py``` to create it or manually.

# Limitations

* Only .bmp format is currently supported, uncompressed and without color palette.

# Issues, Ideas And Bugs
If you have further ideas or you found some bugs, great! Create a [issue](https://github.com/BlueAndi/esp-rgb-led-matrix/issues) or if you are able and willing to fix it by yourself, clone the repository and create a pull request.

# License
The whole source code is published under the [MIT license](http://choosealicense.com/licenses/mit/).
Consider the different licenses of the used third party libraries too!

# Contribution
Unless you explicitly state otherwise, any contribution intentionally submitted for inclusion in the work by you, shall be licensed as above, without any
additional terms or conditions.

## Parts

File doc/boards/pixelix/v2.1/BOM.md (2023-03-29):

# PIXELIX
PIXELIX



# BOM

| Amount | Description | Package | Part | URL |
| --- | --- | --- | --- | --- |
| 1 | Adafruit Feather V2 | Feather V2 | A1 | [Adafruit](https://www.adafruit.com/product/5400), [Amazon](https://www.amazon.de/-/en/Adafruit-ESP32-Feather-V2-8MB-Flash/dp/B0BB2WF9HV/), [Mouser](https://www.mouser.de/ProductDetail/Adafruit/5400?qs=MyNHzdoqoQJczdKY45yRtg%3D%3D) |
| 3 | Capacitor 100 nF | C1206 | C1, C3, C4 | [Reichelt](https://www.reichelt.de/vielschicht-kerko-100nf-50v-125-c-kem-x7r1206b100n-p207152.html?), [Mouser](https://www.mouser.de/ProductDetail/KEMET/C1206C104K5RACTM?qs=ED%252B2xvMfDz2aaotiiWTrQg%3D%3D) |
| 1 | Capacitor 1000 uF / 16 V | E5-8.5 | C2 | [Reichelt](https://www.reichelt.de/elko-radial-1-0-mf-16-v-105-c-low-esr-rad-fr-1-000-16-p121253.html?), [Mouser](https://www.mouser.de/ProductDetail/Panasonic/EEU-FR1C102L?qs=ATUT3BIXiFhT8tblOBeOAQ%3D%3D) |
| 4 | Resistor 100 Ohm | R1206 | R5, R6, R7, R8 | [Reichelt](https://www.reichelt.de/smd-widerstand-1206-100-ohm-250-mw-5-smd-1-4w-100-p18242.html?r=1), [Mouser](https://www.mouser.de/ProductDetail/YAGEO/RC1206JR-07100RL?qs=afJZr%2F7kGG7feudZTJCmlw%3D%3D) |
| 1 | Resistor 1 kOhm | R1206 | R2 | [Reichelt](https://www.reichelt.de/smd-widerstand-1206-1-0-kohm-250-mw-5-smd-1-4w-1-0k-p18221.html?r=1), [Mouser](https://www.mouser.de/ProductDetail/YAGEO/RC1206JR-071KL?qs=CteSnpDdeuB6ARqGTIgKSQ%3D%3D)  |
| 1 | Resistor 1.2 kOhm | R1206 | R3 | [Reichelt](https://www.reichelt.de/smd-widerstand-1206-1-2-kohm-250-mw-5-smd-1-4w-1-2k-p18227.html?r=1), [Mouser](https://www.mouser.de/ProductDetail/YAGEO/RC1206JR-071K2L?qs=CteSnpDdeuDgiTTZVtL9%2FQ%3D%3D)  |
| 1 | Resistor 10 kOhm | R1206 | R1 | [Reichelt](https://www.reichelt.de/smd-widerstand-1206-10-kohm-250-mw-5-smd-1-4w-10k-p18244.html?r=1), [Mouser](https://www.mouser.de/ProductDetail/YAGEO/RC1206JR-0710KL?qs=afJZr%2F7kGG7jis1hiCdUVA%3D%3D) |
| 1 | Resistor 100 kOhm | R1206 | R4 | [Reichelt](https://www.reichelt.de/smd-widerstand-1206-100-kohm-250-mw-1-koa-rk73h2bttd14-p238058.html?), [Mouser](https://www.mouser.de/ProductDetail/YAGEO/RC1206FR-07100KL?qs=XiHlnyMtlzIPjdId8aaAEA%3D%3D) |
| 1 | ESD suppressor CDSOD323-T05C | SOD-323 | D1 | [Conrad](https://www.conrad.de/de/p/bourns-tvs-diode-cdsod323-t05c-sod-323-6-v-350-w-1055444.html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), [Farnell](https://de.farnell.com/bourns/cdsod323-t05c/tvs-diode-bidir-1-line-5v-sod323/dp/1824860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), [Mouser](https://www.mouser.de/ProductDetail/Bourns/CDSOD323-T05C?qs=N%252BiqXe0%252BQtutiz%2Fj8zPmAQ%3D%3D) |
| 1 | Micro fuse block, 4A slow | OMNI-BLOK | F1 | [Reichelt](https://www.reichelt.de/smd-sicherungshalter-mit-sicherung-4-0-a-125-v-traege-litt-0154004-drt-p229203.html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), [Farnell](https://de.farnell.com/littelfuse/0154004-drt/sicherung-smd-omni-block-t-4a/dp/9943765?st=smd%20OMNI-BLOK), [Mouser](https://www.mouser.de/ProductDetail/?qs=gu7KAQ731UQeedYeniUNnQ%3D%3D) |
| 1 | Espressif ESP32-DEVKIT | ESP32-DEVKITC-32D | U1 | [Mouser](https://www.mouser.de/ProductDetail/Espressif-Systems/ESP32-DevKitC-32D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), [Amazon](https://www.amazon.de/s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) |
| 1 | N-channel mosfet BSS138 | SOT23 | Q1 | [Reichelt](https://www.reichelt.de/mosfet-n-ch-50v-0-22a-0-36w-sot-23-bss-138-smd-p41437.html?), [Farnell](https://de.farnell.com/on-semiconductor/bss138/mosfet-n-kanal-50v-220ma-sot-23/dp/9845330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), [Mouser](https://www.mouser.de/ProductDetail/onsemi-Fairchild/BSS138?qs=HK%252BeIG1iaahCeqBvjB4arg%3D%3D) |
| 1 | P-channel mosfet STD26P3LLH6 | TO252 | Q2 | [Reichelt](https://www.reichelt.de/mosfet-p-ch-30v-12a-0-03r-to252-std26p3llh6-p254904.html?), [Farnell](https://de.farnell.com/stmicroelectronics/std26p3llh6/mosfet-p-kanal-30v-12a-to-252/dp/2629747?st=STD26P3LLH6), [Mouser](https://www.mouser.de/ProductDetail/STMicroelectronics/STD26P3LLH6?qs=DqCdCwOw4%2F7LRzP66tTiGg%3D%3D) |
| 5 | Conn_01x02 | Wuerth Elektronik 66200211022 | J1, J2, J4, J6, J8 | [Farnell](https://de.farnell.com/wurth-elektronik/66200211022/steckv-stiftleiste-2pos-1reihe/dp/2827850?ost=66200211022), [Mouser](https://www.mouser.de/c/?q=66200211022) |
| 2 | Conn_01x03 | Wuerth Elektronik 66200311022 | J3, J7 | [Farnell](https://de.farnell.com/wurth-elektronik/66200311022/stiftleiste-abgew-3pos-1-reihe/dp/3818193?ost=66200311022), [Mouser](https://www.mouser.de/ProductDetail/Wurth-Elektronik/66200311022?qs=3RJ0PdSuLVkSi7ZZT4Z8xA%3D%3D) |
| 1 | Conn_02x05_Odd_Even | Wuerth Elektronik 61201021621 | J5 | [Farnell](https://de.farnell.com/wurth-elektronik/61201021621/stiftleiste-2-54mm-gerade-10pol/dp/1642019?ost=61201021621), [Mouser](https://www.mouser.de/ProductDetail/Wurth-Elektronik/61201021621?qs=W%252B2sBeLta1a0dwX5pxbfXw%3D%3D) |
| --- | --- | --- | --- | --- |
| 5 | Plug_01x02 | Wuerth Elektronik 662002013322 | J1*, J2*, J4*, J6*, J8* | [Mouser](https://www.mouser.de/ProductDetail/Wurth-Elektronik/662002013322?qs=2kOmHSv6VfRYc3%2FxPP%2FegA%3D%3D) |
| 2 | Plug_01x03 | Wuerth Elektronik 662003013322 | J3*, J7* | [Mouser](https://www.mouser.de/ProductDetail/Wurth-Elektronik/662003013322?qs=E2PpAYvlWVvj7tqTtujsuA%3D%3D) |
| 1 | WS2812B 5050 8x32 RGB Flexible LED Panel Matrix | - | - | [Amazon](https://www.amazon.de/CHINLY-Flexible-Individuellement-adressable-%C3%A9clairage/dp/B07418XNJ2/) |
| 1 | Power supply 5 V / 5 A (4 A would be enough) | - | - | [Reichelt](https://www.reichelt.de/tischnetzteil-25-w-5-v-5-a-mw-gst40a05-p171043.html?&trstct=pol_1), [Mouser](https://www.mouser.de/ProductDetail/CUI-Inc/SDM36-5-U-P5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) |
| 1 | Power cable | - | - | [Reichelt](https://www.reichelt.de/netzkabel-schutzkontaktstecker-gew-1-8-m-schw-c13-nksk-200-sw-p13490.html?r=1), [Mouser](https://www.mouser.de/ProductDetail/Qualtek/364002-D01?qs=HFfMDpzxxd3ZLZg3BXSDag%3D%3D) |
| 1 | Power supply plug | - | - | [Mouser](https://www.mouser.de/ProductDetail/CUI-Devices/PJ-065A?qs=WyjlAZoYn53baW2eG%252Bovnw%3D%3D) |
| 1 | USER-Button | - | - | [Amazon](https://www.amazon.de/-/en/gp/product/B08L49F7DV) |
| 1 | RESET-Button | - | - | [Amazon](https://www.amazon.de/-/en/gp/product/B08YMZGLWX) |
| 1 | Light Sensor  | LDR5528  | - | [Amazon](https://www.amazon.de/-/en/AZDelivery-pieces-resistor-diodes-LDR5528/dp/B089YNCYG4) |
| 1 | Audio Sensor-Module | INMP441  | - | [Amazon](https://www.amazon.de/-/en/gp/product/B09JFDJ9BF) |
| 4 | Insert-Nuts M2 | - | - | [Amazon](https://www.amazon.de/ruthex-Gewindeeinsatz-St%C3%BCck-Gewindebuchsen-Kunststoffteile/dp/B088QJG676/)

* Note, only **ONE** ESP32 is required. Either U1 or A1.
* Note, you can also use the *Molex 2157601002* connectors for J1, J2, J4, J6 and J8 and the *Molex 2157601003* for J3 and J7.
* Note, you can also use the *Molex 2157591002* plugs for J1*, J2*, J4*, J6* and J8* and the *Molex 2157591003* for J3* and J7*. You also need crimp terminals (e.g. *Wuerth Elektronik 66200113722DEC* or *Molex 2064600021*)
* Do **NOT** combine connectors and plugs from Molex and Wuerth Elektronik!

# Issues, Ideas And Bugs
If you have further ideas or you found some bugs, great! Create a [issue](https://github.com/BlueAndi/esp-rgb-led-matrix/issues) or if you are able and willing to fix it by yourself, clone the repository and create a pull request.

# License
The whole source code is published under the [MIT license](http://choosealicense.com/licenses/mit/).

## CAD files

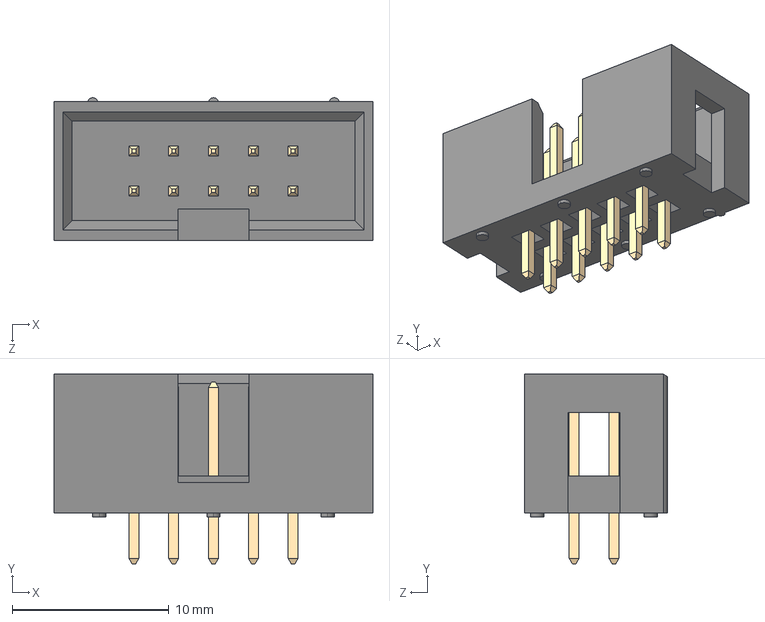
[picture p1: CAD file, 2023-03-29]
doc/boards/pixelix/v2.1/3D-files/61201021621.step
20.4 x 12.1 x 9.10 mm

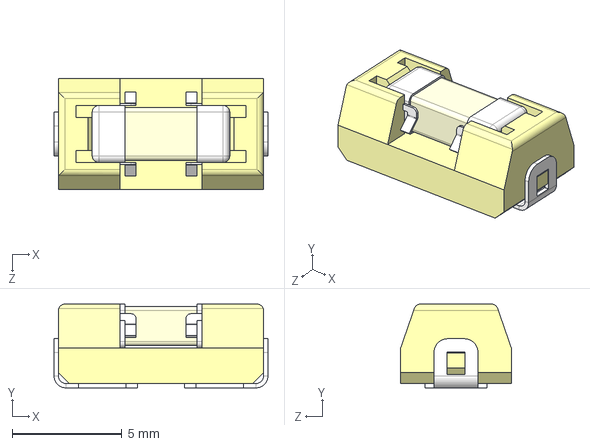
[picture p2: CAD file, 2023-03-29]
doc/boards/pixelix/v2.1/3D-files/0154004.DR.step
9.73 x 3.81 x 5.03 mm

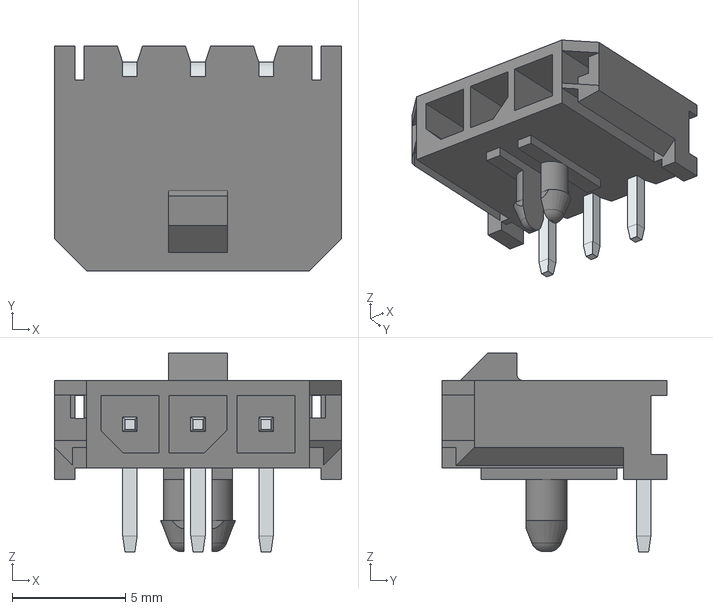
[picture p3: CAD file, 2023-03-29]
doc/boards/pixelix/v2.1/3D-files/66200311022.step
12.7 x 9.90 x 8.76 mm

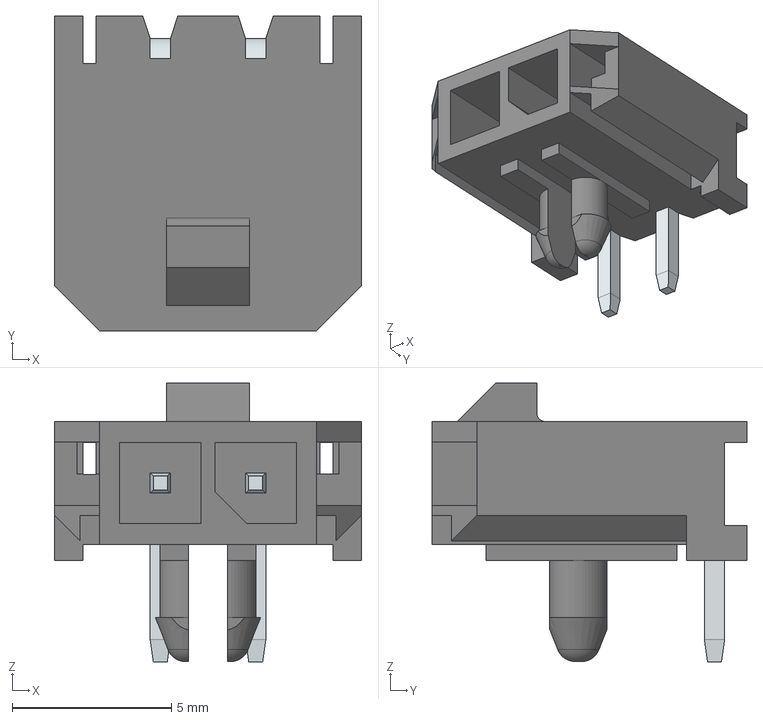
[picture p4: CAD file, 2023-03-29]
doc/boards/pixelix/v2.1/3D-files/66200211022.step
9.65 x 9.90 x 8.76 mm

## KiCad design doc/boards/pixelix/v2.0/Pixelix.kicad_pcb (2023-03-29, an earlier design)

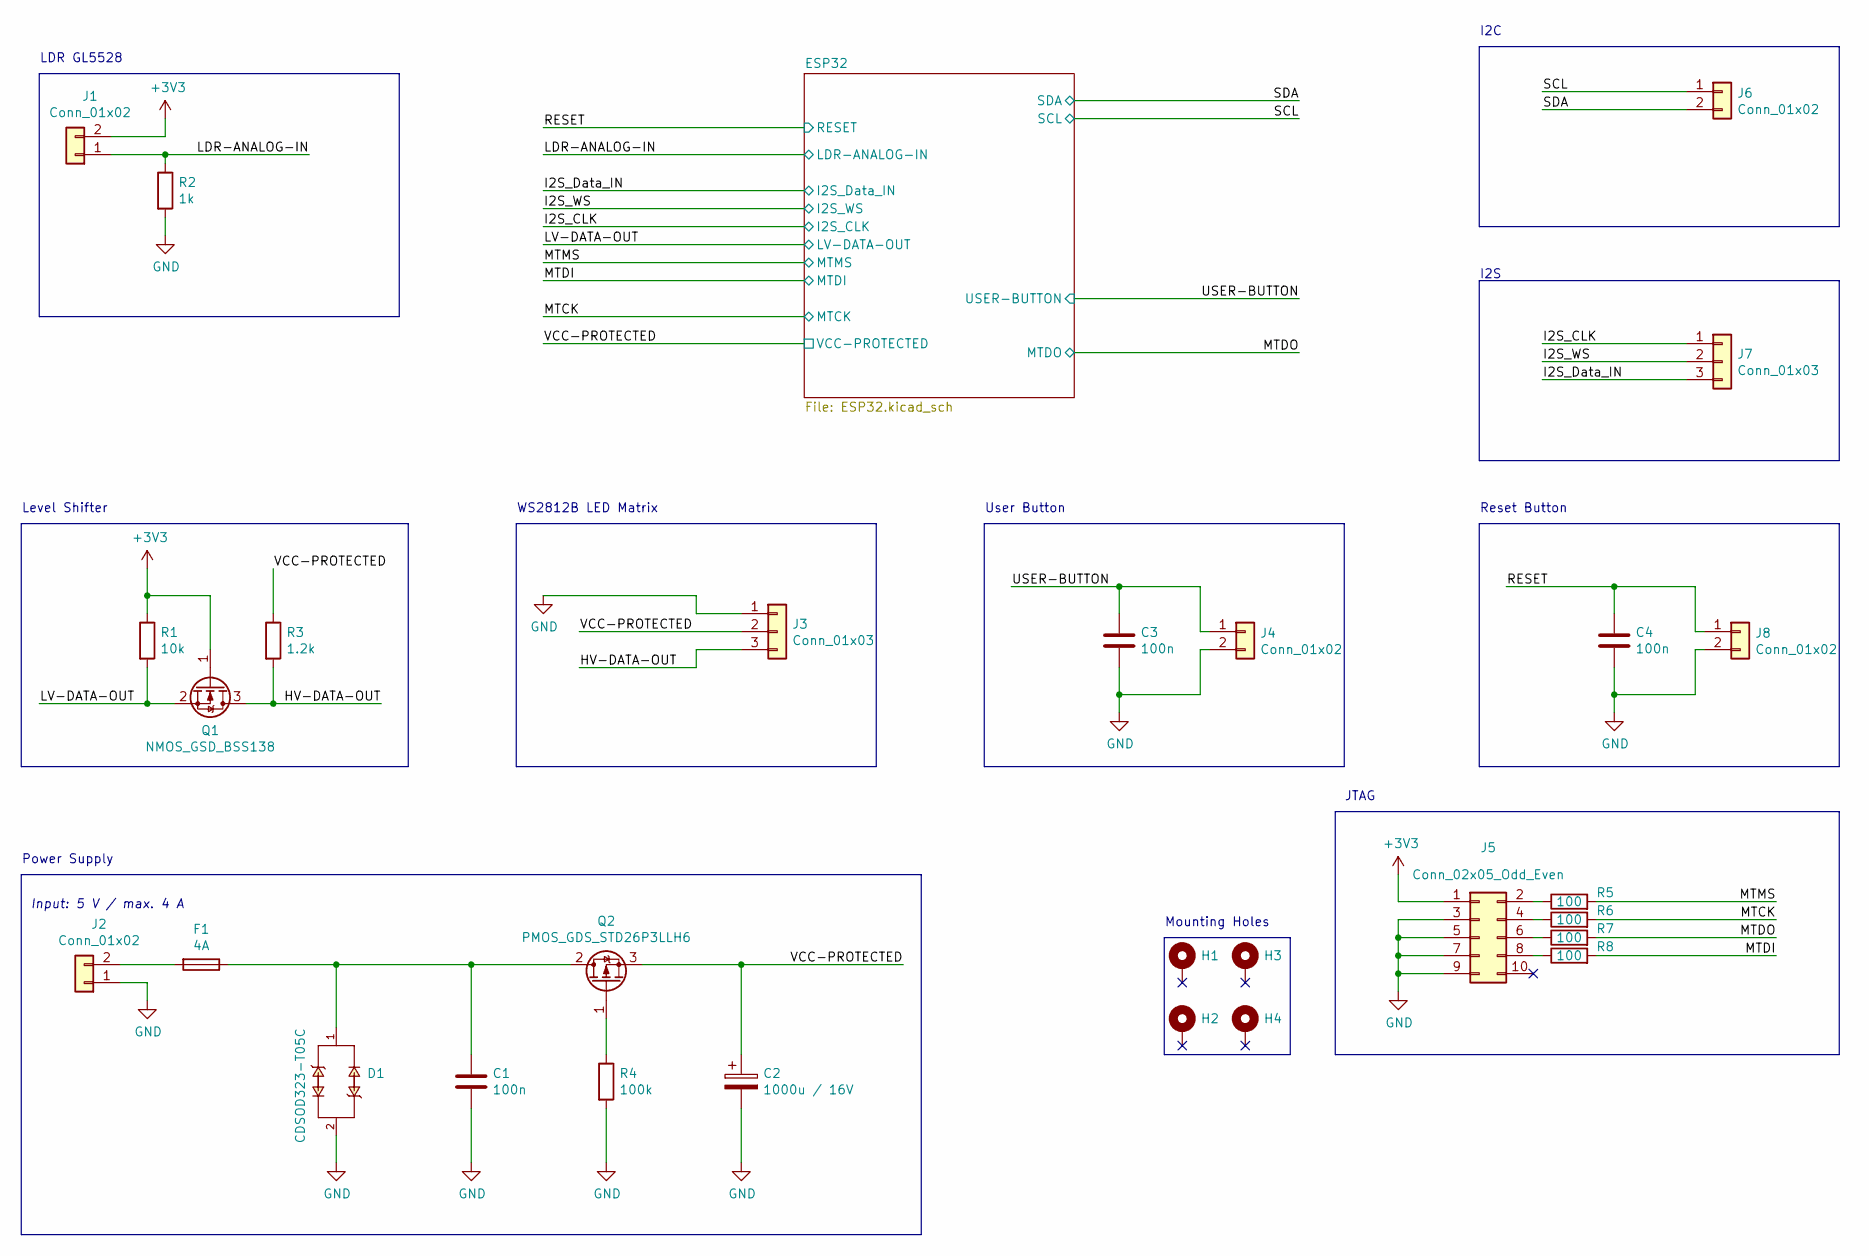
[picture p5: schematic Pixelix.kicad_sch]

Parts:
C1, C3, C4: 100n; C_1206_3216Metric_Pad1.33x1.80mm_HandSolder; Part-No. X7R1206B100N
C2: 1000u / 16V; CP_Radial_D8.0mm_P3.50mm_horizontal; Part-No. EEU-FR1C102L
D1: CDSOD323-T05C; Part-No. CDSOD323-T05C
F1: 4A; FUSE_0154004.DR; Part-No. 0154004.DRT
H1, H2, H3, H4: MountingHole_Pad; MountingHole_2.2mm_M2_Pad_Via
J1, J2, J4, J6, J8: Conn_01x02; 66200211022; Part-No. 66200211022
J3, J7: Conn_01x03; 66200311022; Part-No. 66200311022
J5: Conn_02x05_Odd_Even; 61201021621; Part-No. 61201021621
Q1: NMOS_GSD_BSS138; SOT-23_Handsoldering; Part-No. BSS138
Q2: PMOS_GDS_STD26P3LLH6; TO-252-3_TabPin2; Part-No. STD26P3LLH6
R1: 10k; R_1206_3216Metric_Pad1.30x1.75mm_HandSolder; Part-No. RC1206JR-0710KL
R2: 1k; R_1206_3216Metric_Pad1.30x1.75mm_HandSolder; Part-No. RC1206JR-071KL
R3: 1.2k; R_1206_3216Metric_Pad1.30x1.75mm_HandSolder; Part-No. RC1206JR-071K2L
R4: 100k; R_1206_3216Metric_Pad1.30x1.75mm_HandSolder; Part-No. RK73H2BTTD14
R5, R6, R7, R8: 100; R_1206_3216Metric_Pad1.30x1.75mm_HandSolder; Part-No. RC1206JR-07100RL

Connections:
+3V3: J1.2, J5.1, Q1.1 (G), R1.1; also elsewhere on the board
/HV-DATA-OUT: J3.3, Q1.3 (D), R3.2
/I2S_CLK: J7.1; also elsewhere on the board
/I2S_Data_IN: J7.3; also elsewhere on the board
/I2S_WS: J7.2; also elsewhere on the board
/LDR-ANALOG-IN: J1.1, R2.1; also elsewhere on the board
/LV-DATA-OUT: Q1.2 (S), R1.2; also elsewhere on the board
/MTCK: R6.2; also elsewhere on the board
/MTDI: R8.2; also elsewhere on the board
/MTDO: R7.2; also elsewhere on the board
/MTMS: R5.2; also elsewhere on the board
/RESET: C4.1, J8.1; also elsewhere on the board
/SCL: J6.1; also elsewhere on the board
/SDA: J6.2; also elsewhere on the board
/USER-BUTTON: C3.1, J4.1; also elsewhere on the board
/VCC-PROTECTED: C2.1, J3.2, Q2.3 (S), R3.1; also elsewhere on the board
GND: C1.2, C2.2, C3.2, C4.2, D1.2, J2.1, J3.1, J4.2, J5.3, J5.5, J5.7, J5.9, J8.2, R2.2, R4.2; also elsewhere on the board
unnamed: C1.1, D1.1, F1.1, Q2.2 (D)
unnamed: F1.2, J2.2
unnamed: J5.2, R5.1
unnamed: J5.4, R6.1
unnamed: J5.6, R7.1
unnamed: J5.8, R8.1
unnamed: Q2.1 (G), R4.1

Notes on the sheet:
User Button
LDR GL5528
WS2812B LED Matrix
I2S
JTAG
I2C
Power Supply
Mounting Holes
Input: 5 V / max. 4 A
Level Shifter
Reset Button

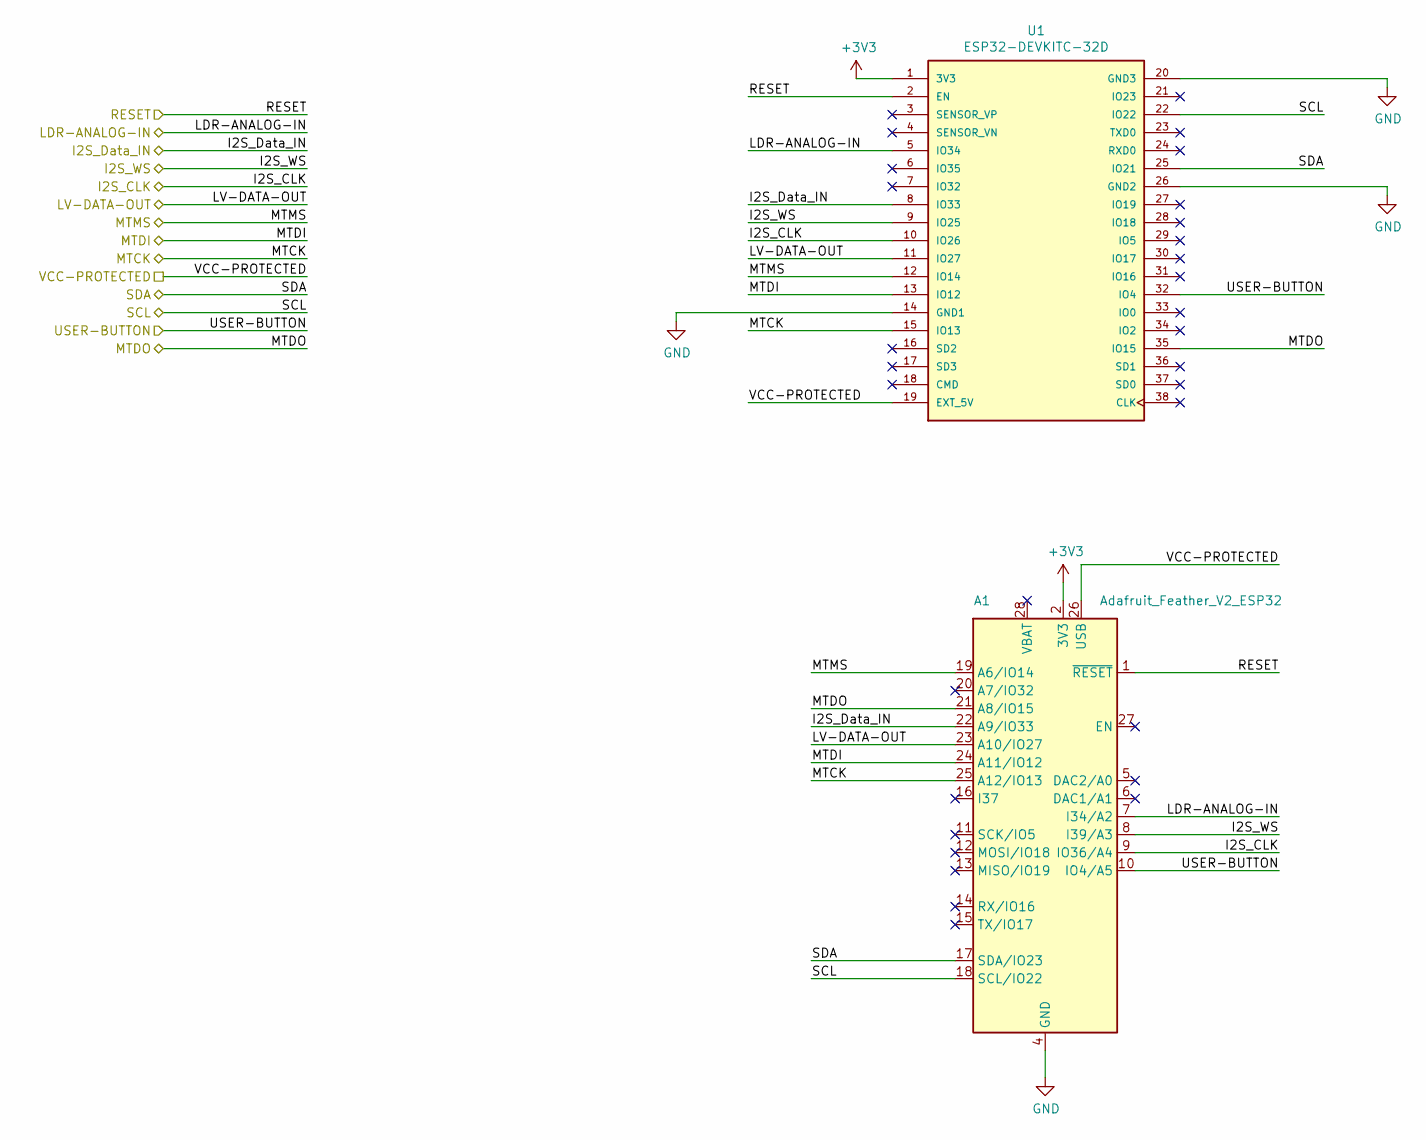
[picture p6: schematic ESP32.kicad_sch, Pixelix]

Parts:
A1: Adafruit_Feather_V2_ESP32; Part-No. Feather V2
U1: ESP32-DEVKITC-32D; MODULE_ESP32-DEVKITC-32D; Part-No. ESP32-DEVKITC-32D

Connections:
+3V3: A1.2 (3V3), U1.1 (3V3); also elsewhere on the board
/I2S_CLK: A1.9 (IO36/A4), U1.10 (IO26); also elsewhere on the board
/I2S_Data_IN: A1.22 (A9/IO33), U1.8 (IO33); also elsewhere on the board
/I2S_WS: A1.8 (I39/A3), U1.9 (IO25); also elsewhere on the board
/LDR-ANALOG-IN: A1.7 (I34/A2), U1.5 (IO34); also elsewhere on the board
/LV-DATA-OUT: A1.23 (A10/IO27), U1.11 (IO27); also elsewhere on the board
/MTCK: A1.25 (A12/IO13), U1.15 (IO13); also elsewhere on the board
/MTDI: A1.24 (A11/IO12), U1.13 (IO12); also elsewhere on the board
/MTDO: A1.21 (A8/IO15), U1.35 (IO15); also elsewhere on the board
/MTMS: A1.19 (A6/IO14), U1.12 (IO14); also elsewhere on the board
/RESET: A1.1 (~RESET), U1.2 (EN); also elsewhere on the board
/SCL: A1.18 (SCL/IO22), U1.22 (IO22); also elsewhere on the board
/SDA: A1.17 (SDA/IO23), U1.25 (IO21); also elsewhere on the board
/USER-BUTTON: A1.10 (IO4/A5), U1.32 (IO4); also elsewhere on the board
/VCC-PROTECTED: A1.26 (USB), U1.19 (EXT_5V); also elsewhere on the board
GND: A1.4 (GND), U1.14 (GND1), U1.20 (GND3), U1.26 (GND2); also elsewhere on the board

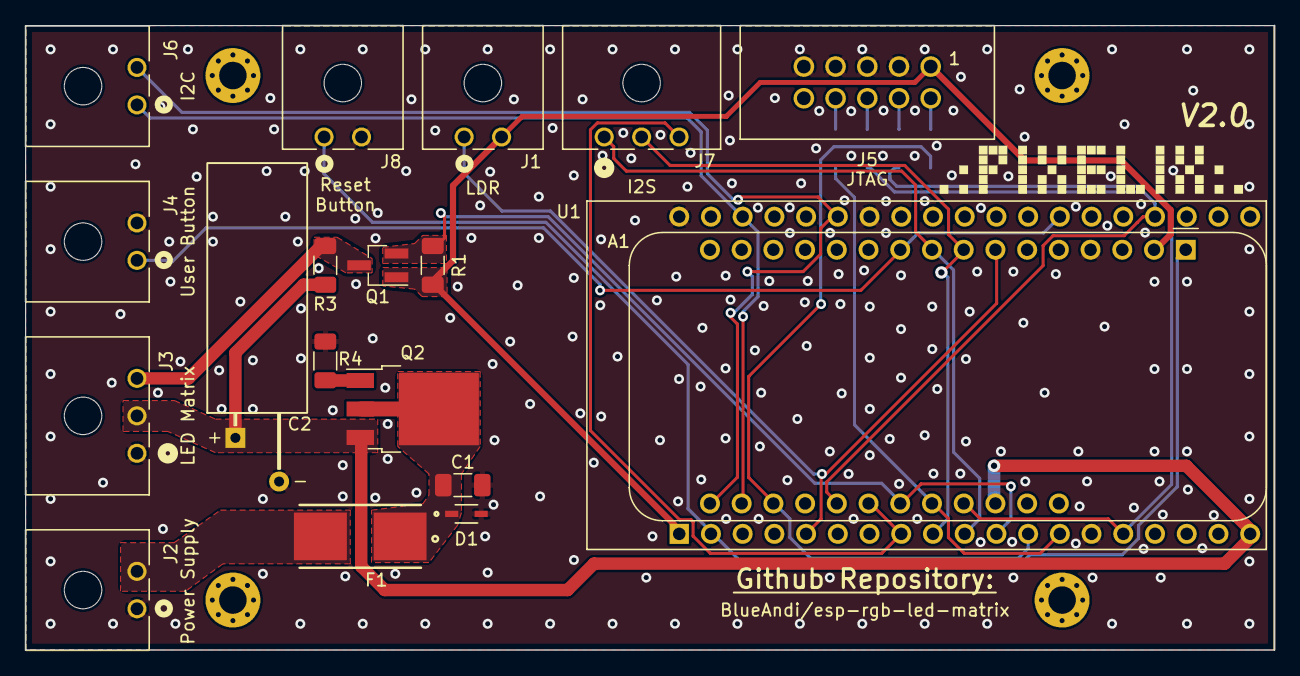
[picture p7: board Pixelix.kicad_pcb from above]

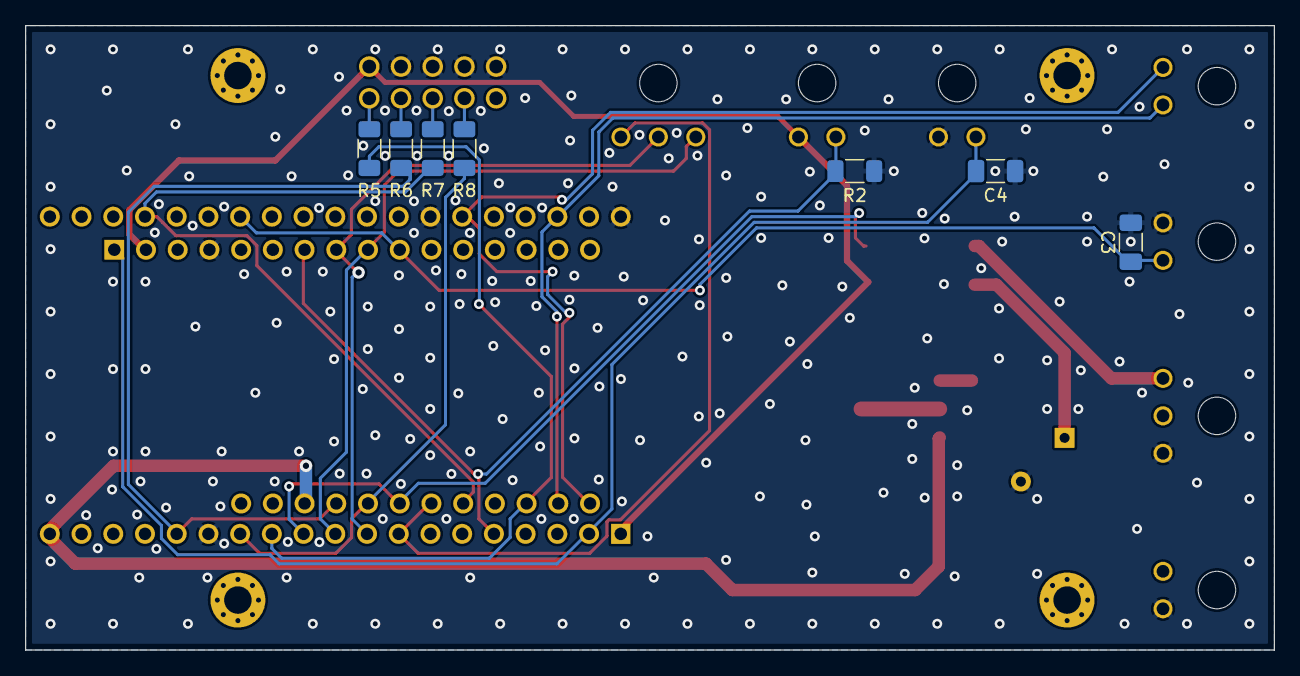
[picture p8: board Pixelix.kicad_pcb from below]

Board: 2 copper layers, 100.0 x 50.0 mm, 30 parts (7 on the bottom side), 24 nets.

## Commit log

2020-11-16 The LED matrix layout can now be configured during runtime. Note, if the corresponding setting is changed via web interface, a reboot is necessary.
2023-03-29 Renormalized Line Endings
    [0154004.DR.step, 61201021621.step, 66200211022.step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]

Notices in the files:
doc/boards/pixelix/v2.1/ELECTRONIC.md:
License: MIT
